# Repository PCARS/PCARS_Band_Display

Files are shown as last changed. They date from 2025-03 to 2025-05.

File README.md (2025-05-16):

# PCARS W4MLB Club Station Band Display

## Technical Project Summary

This project was developed for the Platinum Coast Amateur Radio Club (PCARS) to improve operational coordination at the W4MLB Club Station. It features a shared LED display that shows the active operating band and mode for two radio stations (Station 1 and Station 2), helping operators avoid frequency conflicts and manage dual-station operation more effectively.

---

## System Overview

The Band Display system consists of:

1. **ESP32-Based Control Unit**  
2. **Single Shared 64x64 RGB LED Matrix Display**  
3. **Audible Conflict Alert System**

<table>
  <tr>
    <td align="center">
      <br/>
      <sub>PCARS Band Display</sub>
    </td>
  </tr>
</table>

---

## Hardware Details

### Microcontroller
- **ESP32 DevKit V1**
  - Dual-core 32-bit microcontroller with Wi-Fi and Bluetooth
  - Interfaces with both radios via CI-V communication over UART
  - Processes band/mode data and drives the shared LED matrix display and alert system

### Display System
- **Single 64x64 RGB LED Matrix (HUB75 interface)**
  - Displays operating band and mode for both stations side-by-side
  - Color-coded segments for easy visual distinction between Station 1 and Station 2
  - Driven using the [ESP32-HUB75-MatrixPanel-I2S-DMA library](https://github.com/mrfaptastic/ESP32-HUB75-MatrixPanel-I2S-DMA) for high-performance, flicker-free display updates

### Radio Interface (Band/Mode Input)
- **CI-V Serial Bus Communication**
  - Each radio communicates band/mode data to the ESP32 via CI-V protocol
  - CI-V signals are connected to separate UART RX/TX pairs on the ESP32
  - Enables automated and accurate detection of each radio’s current state

### Power Supply
- **5V / 5A DC Input via 2.5mm Barrel Jack and Inline Mini Fuse Holder**
- **2-Position Screw Terminal for powering the LED matrix directly**, ensuring stable high-current delivery

### Alert System
- **Passive Buzzer (controlled via GPIO)**
  - Activates after 3 seconds if both stations are tuned to the same band
  - Logic controlled by the ESP32 to help operators avoid interference

### Connectors
- **2x8 Female Header (Bottom) + 2x8 Male Ribbon Header (Top)**
  - Used to interface the ESP32 Control Board to the LED matrix
  - Bottom connector allows direct plug-in to the matrix input (back-side mounting)
  - Top connector allows connection via standard ribbon cable

### PCB Design
- **2-layer Custom PCB**
  - Top layer features a +5V copper fill for power distribution
  - Bottom layer contains a solid ground pour with signal traces routed within
  - Compact and purpose-built layout for minimal noise and easy integration with the LED matrix

## Key Features
- Shared 64x64 LED matrix with real-time band/mode display for both stations  
- CI-V-based band/mode input over UART for accurate radio status monitoring  
- Conflict alert system buzzer with 3-second delay 
- ESP32-driven logic with efficient HUB75 display handling  
- Clean power distribution with dedicated matrix power input

## Software

The Band Display firmware is developed using the **Arduino framework** within **PlatformIO** on **Microsoft Visual Studio Code**. It leverages the multitasking capabilities of the ESP32 and includes purpose-built logic for real-time display updates, radio state monitoring, and conflict alerts.

### Key Components

- **PlatformIO Environment**  
  Ensures reproducible builds and dependency management.  
  Configuration is defined in `platformio.ini`.

- **ESP32-HUB75-MatrixPanel-I2S-DMA Library**  
  Handles high-speed updates to the 64x64 HUB75 RGB LED matrix.  
  This library utilizes the **ESP32's built-in DMA hardware** to stream pixel data directly to the matrix via the I2S peripheral.  
  Because the DMA engine manages the actual data transfer, the **main processor cores remain free** for other tasks such as serial parsing, logic processing, and display updates.  
  This results in **flicker-free, high-performance rendering** with minimal CPU overhead.  
  GitHub: [ESP32-HUB75-MatrixPanel-I2S-DMA](https://github.com/mrfaptastic/ESP32-HUB75-MatrixPanel-I2S-DMA)

- **CI-V Decoder Logic**  
  Parses incoming CI-V data from both radios over two **dedicated hardware UARTs** on the ESP32.  
  Using hardware UART peripherals ensures that incoming serial data is buffered and handled by the UART hardware itself—**without blocking or interrupting the main program flow**.  
  This allows for **reliable and real-time decoding** of Icom/Yaesu CI-V messages, even when both radios are transmitting data simultaneously.

- **Display Management**  
  Color-coded band/mode segments for each station.  
  Adaptive text sizing and positioning to fit the matrix resolution.  
  Designed to update dynamically based on the latest decoded band and mode data for each station.

- **Conflict Alert System**  
  When both stations are detected operating on the same band, a **passive buzzer** is used to annunciate the conflict.  
  The buzzer is driven using one of the **ESP32’s built-in PWM channels**, which allows tone generation **without burdening the processor with manual timing or waveform control**.  
  This hardware-driven approach ensures accurate and non-blocking sound output, keeping the main application responsive.

- **Task Scheduling**  
  Uses ESP32 FreeRTOS tasks for concurrent handling of:
  - CI-V communication  
  - Display updates  
  - Conflict alert logic  
  This structure allows each subsystem to operate independently without interfering with others, improving responsiveness and reliability.

  ---

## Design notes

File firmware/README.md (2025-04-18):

This folder contains firmware files for the ESP32 DevKit V1 board that is used to drive a 64x64 HUB75 P3 LED Matrix display.

The firmware also interfaces with the radio's CI-V busses by utilizing the onboard HW UARTS of the ESP32.

The firmware listens for changes to frequency and operating mode.

It can also query the radios on startup to initialize the LED display with the proper status information. (band and operating mode)

The firmware will also activate a warning buzzer if both stations are on the same operating band for more than 3 seconds.

The LED Matrix is driven by ESP32-HUB75-MatrixPanel-I2S-DMA library.

The firmware was developed using the Arduino framework utilizing PlatFormIO running inside MS VS Code. See the platformio.ini file for details.

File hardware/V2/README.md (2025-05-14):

This folder contains PCB design files for the PCARS Band Display interface/controller board.

This booard is designed to plug directly into the ribbon cable connector on the back side of a HUB75 LED Matrix.

It is small enough to fit inside the cavity behind the LED Matrix.

The board provide interfaces for CI-V buses from 2 different radios.

The board also has connections for a DC power supply to power the LED Matrix and ESP32 controller.

A passive buzzder is also included to allow for alerting when both radios are tuned to the same band.

The PCB was designed using the KiCAD design suite.

The Library folder contains sub-folders for the individual part's Symbols, Footprints and 3D models.

The parts library files were download primarily from the SnapEDA website.

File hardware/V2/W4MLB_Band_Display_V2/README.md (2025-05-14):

This folder contains PCB design files for the PCARS Band Display interface/controller board.

This booard is designed to plug directly into the ribbon cable connector on the back side of a HUB75 LED Matrix.

It is small enough to fit inside the cavity behind the LED Matrix.

The board provide interfaces for CI-V buses from 2 different radios.

The board also has connections for a DC power supply to power the LED Matrix and ESP32 controller.

A passive buzzder is also included to allow for alerting when both radios are tuned to the same band.

The PCB was designed using the KiCAD design suite.

The Library folder contains sub-folders for the individual part's Symbols, Footprints and 3D models.

The parts library files were download primarily from the SnapEDA website.
### Images:

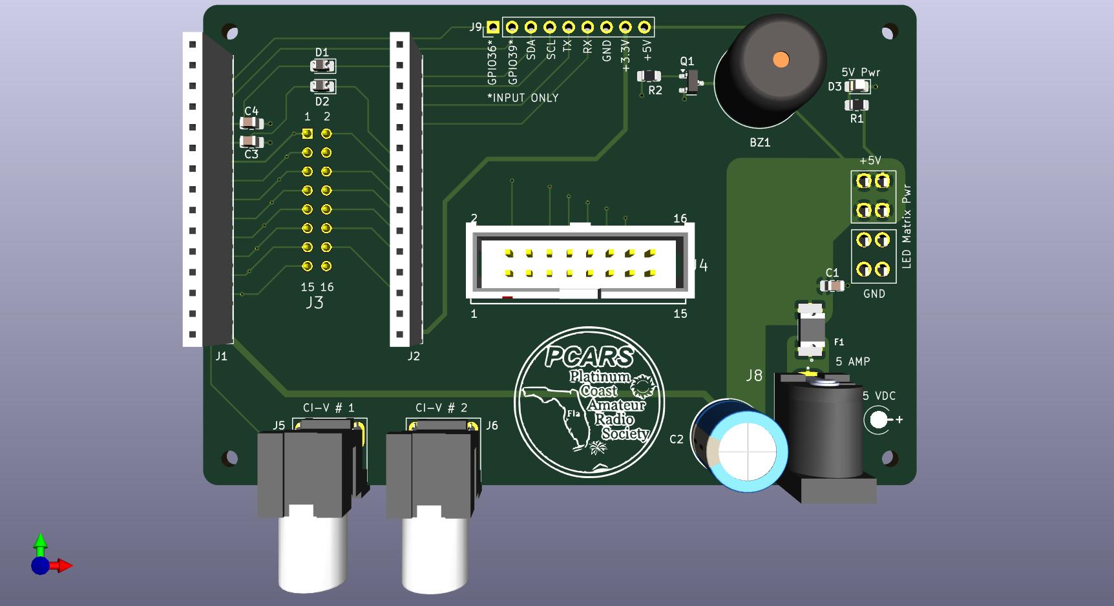
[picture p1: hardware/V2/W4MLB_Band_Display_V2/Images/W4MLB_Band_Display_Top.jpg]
Top View

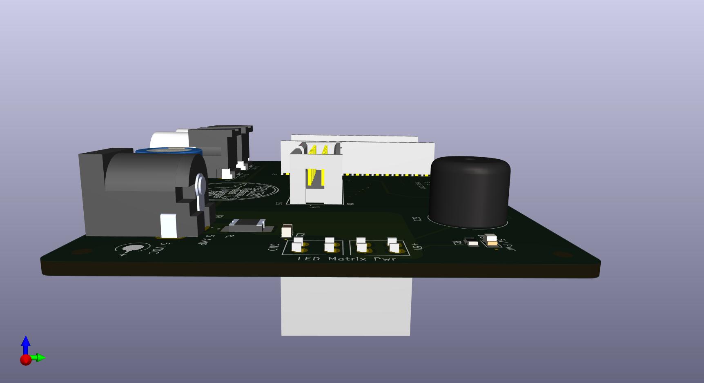
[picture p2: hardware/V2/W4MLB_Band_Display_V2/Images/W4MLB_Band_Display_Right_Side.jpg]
Right Side View

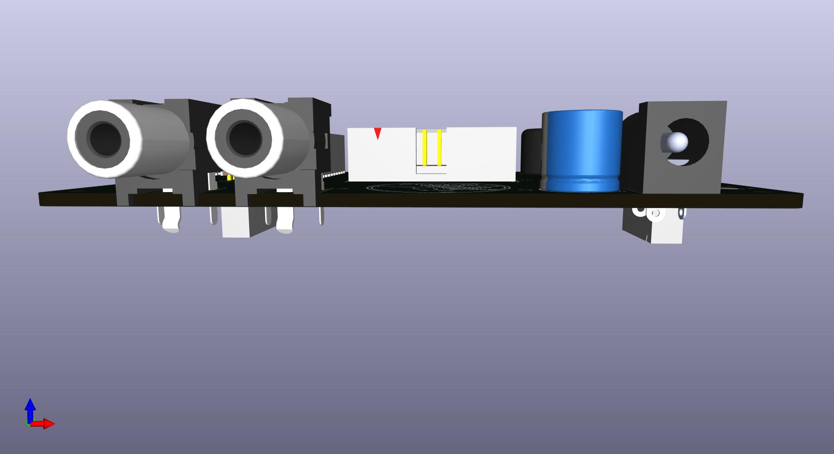
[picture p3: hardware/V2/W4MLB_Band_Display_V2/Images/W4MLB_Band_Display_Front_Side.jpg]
Front Side View

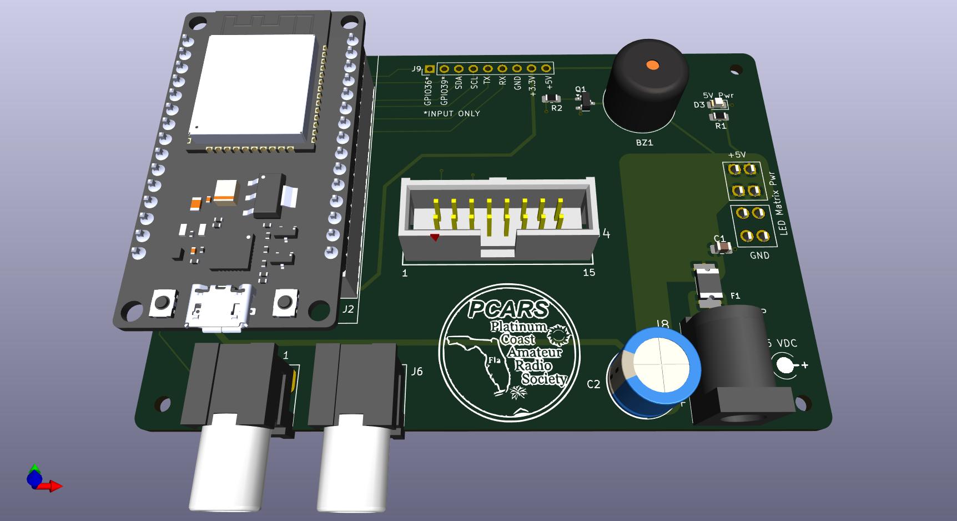
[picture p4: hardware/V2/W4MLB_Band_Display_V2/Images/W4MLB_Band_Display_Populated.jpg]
Populated Board

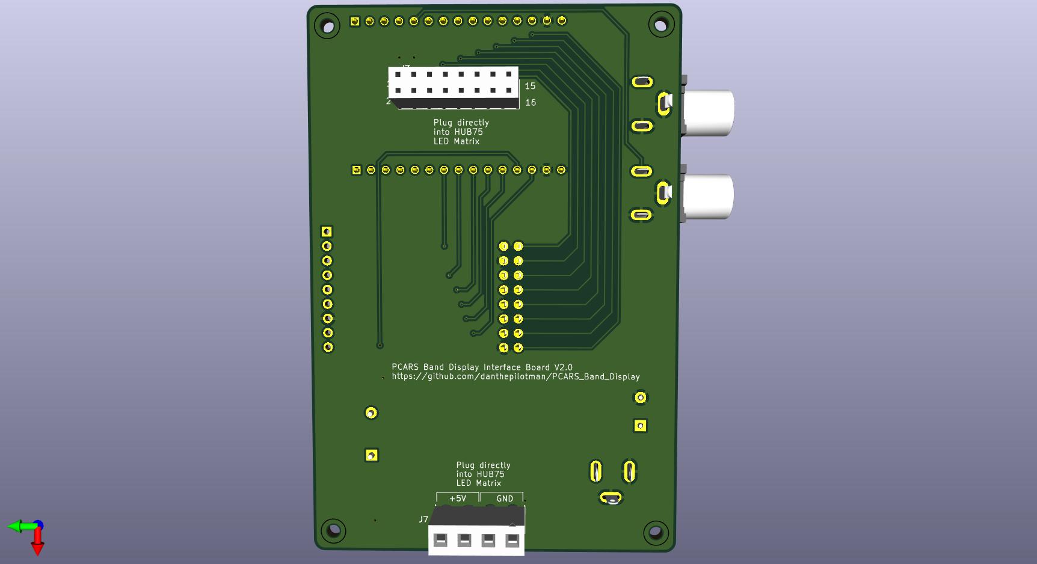
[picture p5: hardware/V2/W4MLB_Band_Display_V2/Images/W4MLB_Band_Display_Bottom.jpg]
Bottom View


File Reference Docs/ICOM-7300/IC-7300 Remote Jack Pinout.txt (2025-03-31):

Tip ->  CI-V data
Ring -> NC
Sleeve -> GND

Connections

    IC-7300 (Remote Jack) → Optocoupler Input

        Tip → Optocoupler Anode (+)

        Sleeve (GND) → Optocoupler Cathode (-)
	
	390Ω current limiting resistor

	R = (5V - 1.2V) / 10mA  
	R = 3.8V / 10mA  
	R = 380Ω (round to 390Ω for safety)

    Optocoupler Output (Transistor Side) → Arduino

        Collector → Arduino RX Pin (e.g., D2 for Radio 1, D3 for Radio 2)

        Emitter → GND

        4.7kΩ Pull-up resistor between the collector and 5V to ensure proper signal reading.

The pull-up resistor for the CI-V bus is inside the radio, but its presence and value depend on the specific Icom model and settings.
Inside the Radio:

    Most Icom radios (including the IC-7300) have an internal pull-up resistor on the CI-V data line.

    The typical value is around 4.7kΩ - 10kΩ, pulling the line up to 5V.

    This allows multiple devices (tuner, amp, PC, etc.) to share the same single-wire bus.

How to Check If a Pull-Up Resistor Exists

    Measure Voltage on the CI-V Tip (Idle State)

        Disconnect any external CI-V devices.

        Use a multimeter to measure the voltage between the tip (data line) and sleeve (ground) of the 3.5mm CI-V jack.

        If the voltage is ~5V, the radio has an internal pull-up.

        If the voltage is ~0V, the radio may not have a pull-up, or it only activates when a device is connected.

    Use an Oscilloscope or Logic Analyzer

        Observe the CI-V bus while the radio transmits data.

        If the high level is weak or unstable, an external pull-up may help.

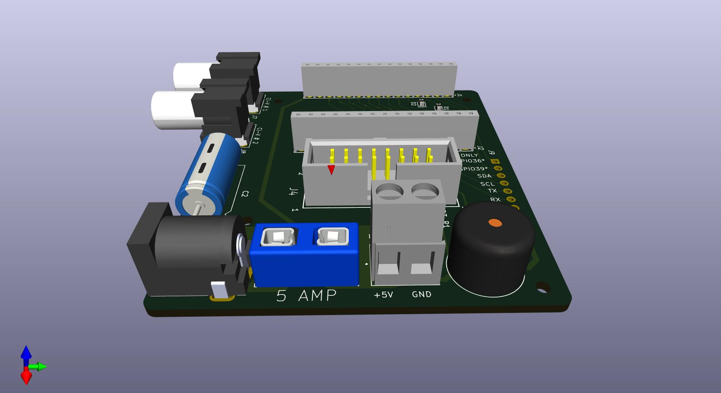
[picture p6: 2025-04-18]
hardware/V2/Images/W4MLB_Band_Display_Right_Side.jpg

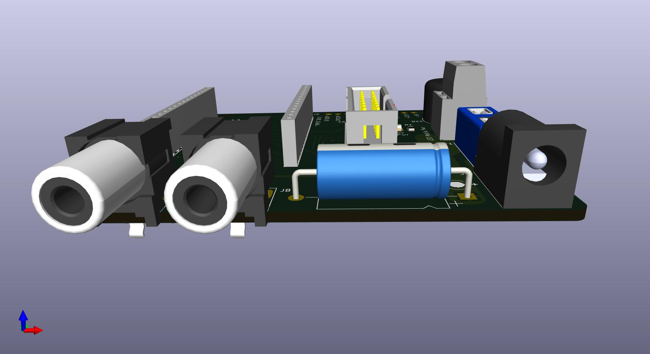
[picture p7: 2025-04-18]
hardware/V2/Images/W4MLB_Band_Display_Front_Side.jpg

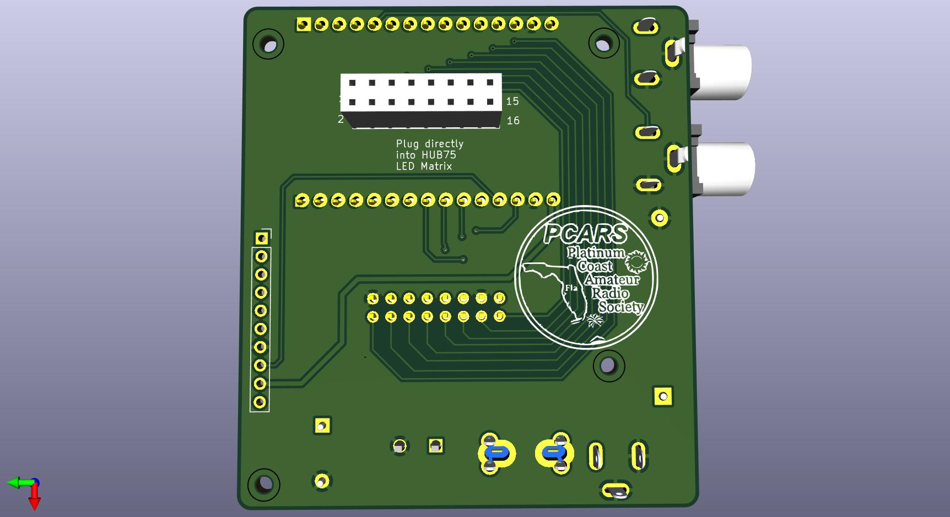
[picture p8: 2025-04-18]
hardware/V2/Images/W4MLB_Band_Display_Bottom.jpg

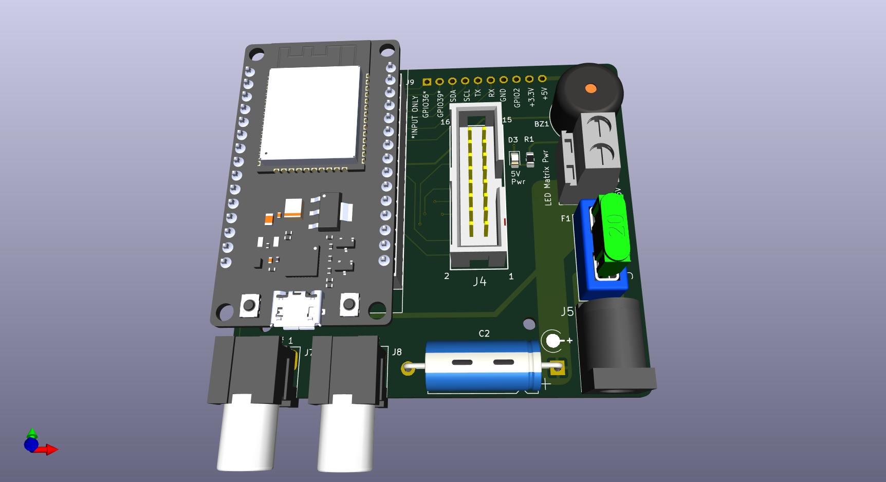
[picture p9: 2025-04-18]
hardware/V2/Images/W4MLB_Band_Display_Populated.jpg

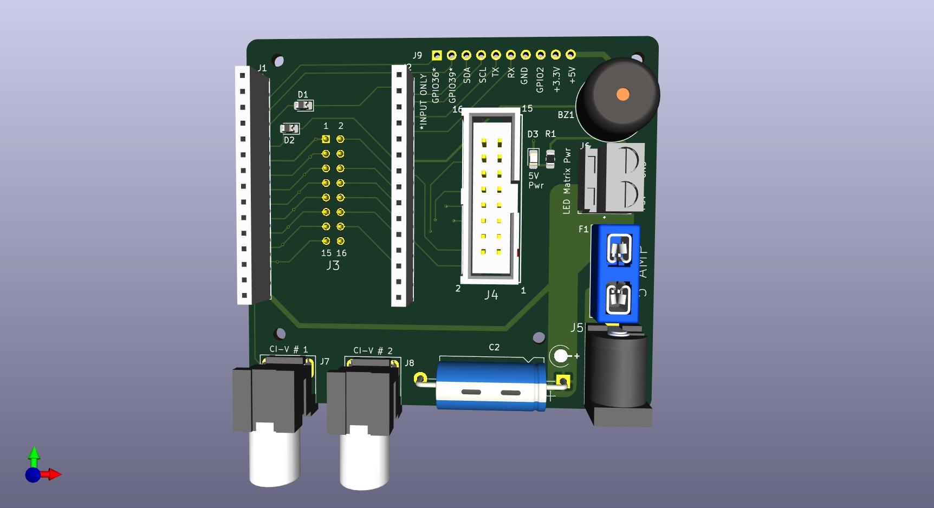
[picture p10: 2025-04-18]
hardware/V2/Images/W4MLB_Band_Display_Top.jpg

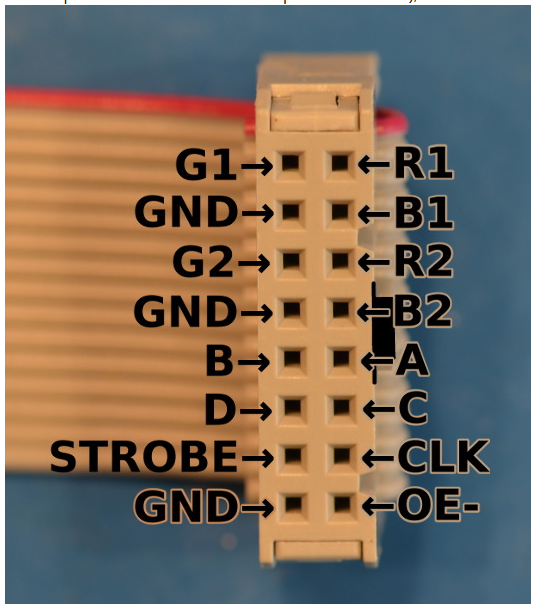
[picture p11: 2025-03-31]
Reference Docs/64x64 LED Matrix Connector Pinout.PNG

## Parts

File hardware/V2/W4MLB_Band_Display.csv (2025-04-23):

Reference | Qty | Value | DNP | Exclude from BOM | Exclude from Board | Footprint | Datasheet
BZ1 | 1 | Buzzer |  |  |  | Buzzer_Beeper:Buzzer_12x9.5RM7.6 | kicad-embed://cmi_1295_05th-3513106.pdf
C1,C3,C4 | 3 | 4.7nF |  |  |  | Capacitor_SMD:C_0805_2012Metric_Pad1.18x1.45mm_HandSolder | kicad-embed://KGM_X7R-3223212.pdf
C2 | 1 | 2200uF |  |  |  | Capacitor_THT:CP_Radial_D10.0mm_P5.00mm | kicad-embed://ABA0000C1218.pdf
D1,D2 | 2 | 1N4001 |  |  |  | Diode_SMD:D_0805_2012Metric_Pad1.15x1.40mm_HandSolder | kicad-embed://TS4148 SERIES_A2301.pdf
D3 | 1 | LED |  |  |  | LED_SMD:LED_0805_2012Metric_Pad1.15x1.40mm_HandSolder | kicad-embed://Lite_On_LTST_C170KGKT-1175299.pdf
F1 | 1 | Polyfuse |  |  |  | Footprints:FUSE_1812L200_12DR | kicad-embed://1812L300SLPR_Littelfuse.pdf
J1,J2 | 2 | SSW-115-01-G-S |  |  |  | Footprints:SAMTEC_SSW-115-01-G-S | kicad-embed://SSW-115-01-G-S_Samtec.pdf
J3 | 1 | SSQ-108-01-T-D-LL |  |  |  | Footprints:SAMTEC_SSQ-108-01-T-D-LL | kicad-embed://SSQ-108-01-T-D-LL_Samtec.pdf
J4 | 1 | SAMTEC-TST-108-01-X-D |  |  |  | Footprints:SAMTEC-TST-108-01-X-D | kicad-embed://tst-1xx-xx-x-x-xx-xx-mkt.pdf
J5,J6 | 2 | PJRAN1X1U01X |  |  |  | Footprints:SWITCHCRAFT_PJRAN1X1U01X | kicad-embed://PJRAN1X1U01X_Switchcraft.pdf
J7 | 1 | 4DB-P108-02 |  |  |  | Footprints:CONN_4DB-P108-02_TEC | 4DB-P108-02
J8 | 1 | EJ503B |  |  |  | Footprints:MPD_EJ503B | kicad-embed://EJ503B_MPD_(Memory.pdf
J9 | 1 | Conn_01x09 |  |  |  | Connector_PinHeader_2.54mm:PinHeader_1x09_P2.54mm_Vertical | ~
Q1 | 1 | MMBT2222A |  |  |  | Package_TO_SOT_SMD:SOT-23 | kicad-embed://mmbt2222.pdf
R1 | 1 | 150 |  |  |  | Resistor_SMD:R_0805_2012Metric_Pad1.20x1.40mm_HandSolder | kicad-embed://crcwce3.pdf
R2 | 1 | 470 |  |  |  | Resistor_SMD:R_0805_2012Metric_Pad1.20x1.40mm_HandSolder | kicad-embed://PYu_AC_51_RoHS_L_9-3005297.pdf
U1 | 1 | ESP32-DEVKIT-V1 | DNP | Excluded from BOM | Excluded from board | Footprints:MODULE_ESP32_DEVKIT_V1

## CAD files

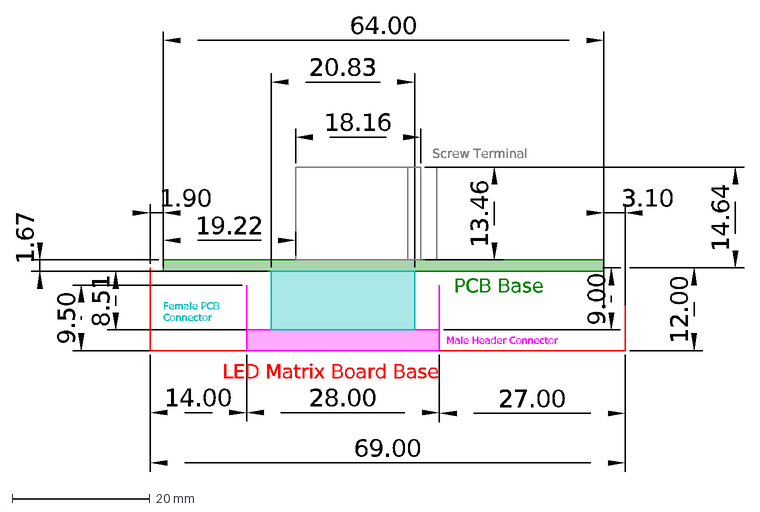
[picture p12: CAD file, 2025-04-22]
hardware/V2/Mechanical_CAD/Mechanical_Stack_Up.dxf
PCB Base
64.00
12.00
14.00
28.00
9.50
69.00
27.00
1.90
9.00
20.83
8.51
Male Header Connector
Female PCB Connector
LED Matrix Board Base
1.67
13.46
19.22
18.16
14.64
3.10
Screw Terminal

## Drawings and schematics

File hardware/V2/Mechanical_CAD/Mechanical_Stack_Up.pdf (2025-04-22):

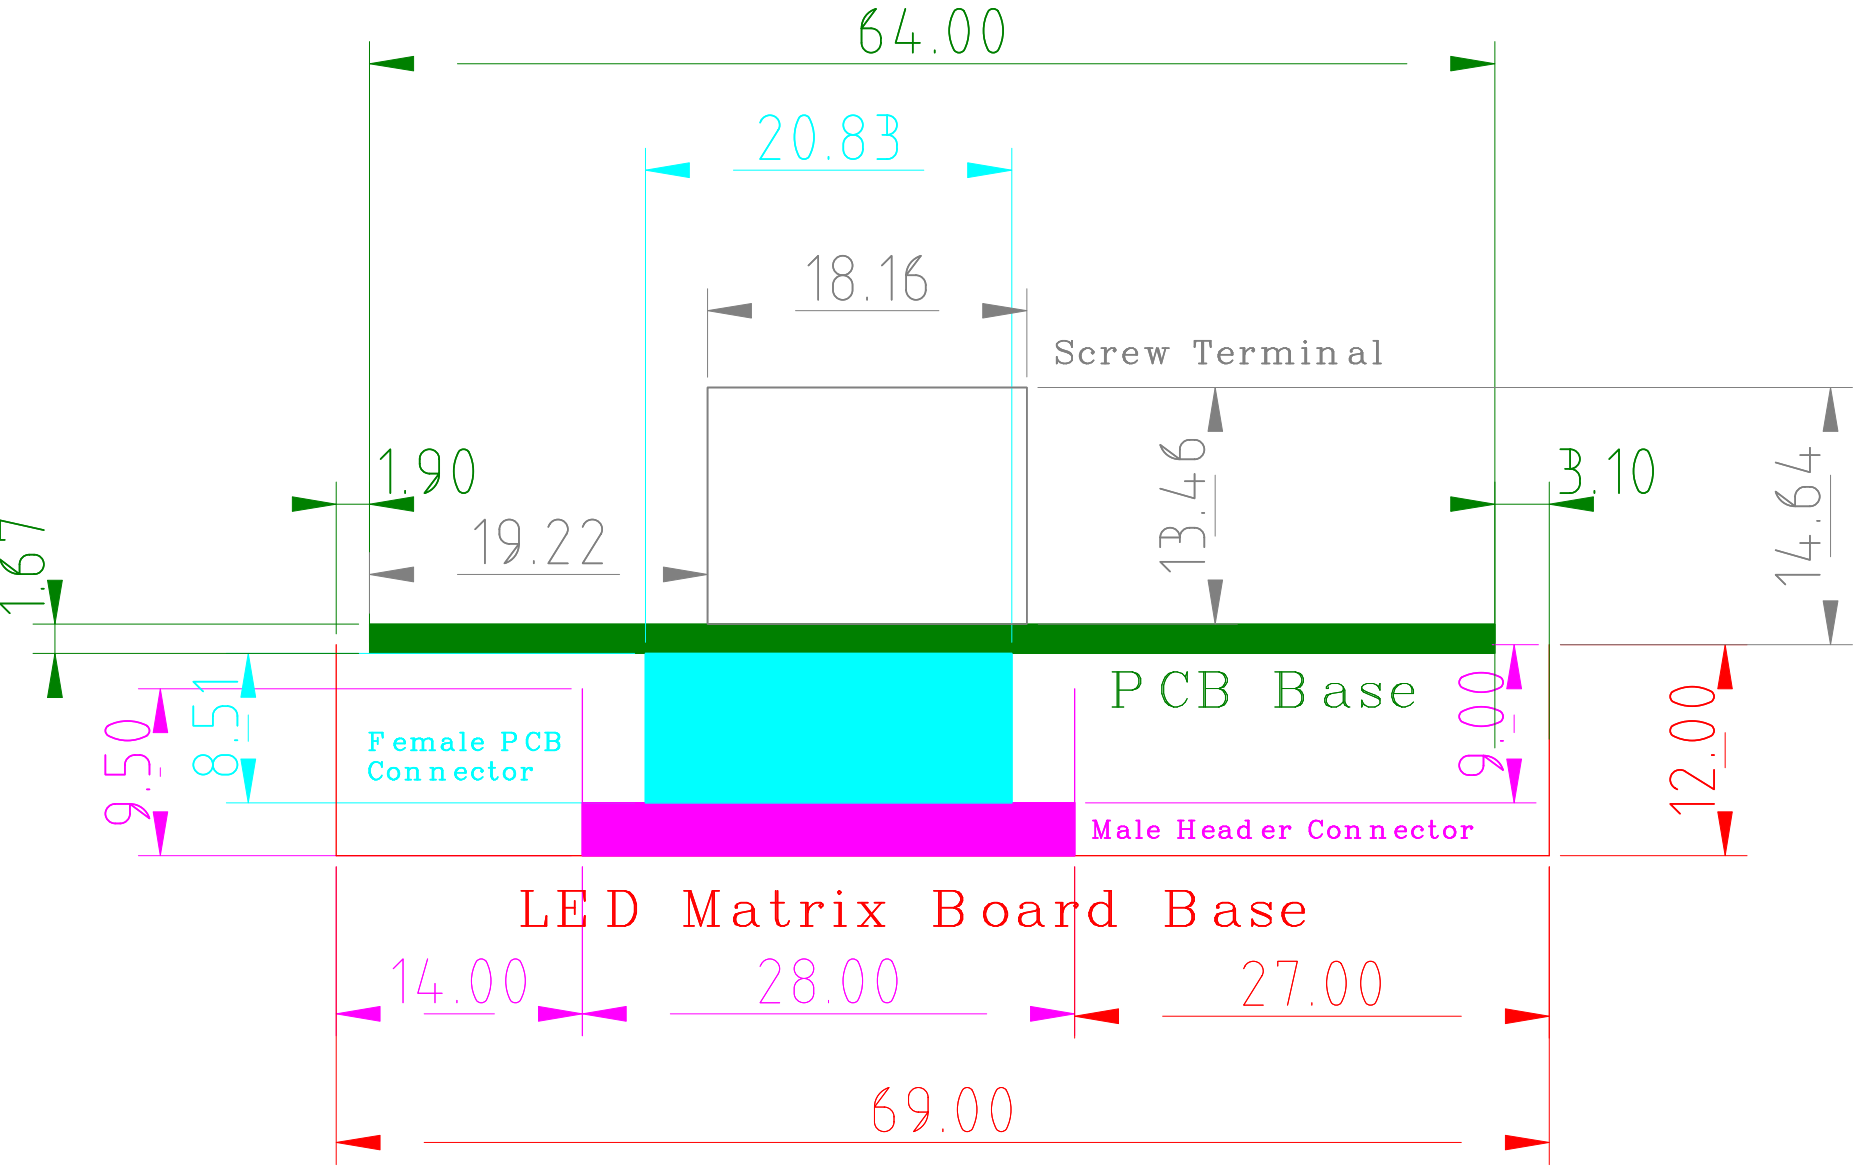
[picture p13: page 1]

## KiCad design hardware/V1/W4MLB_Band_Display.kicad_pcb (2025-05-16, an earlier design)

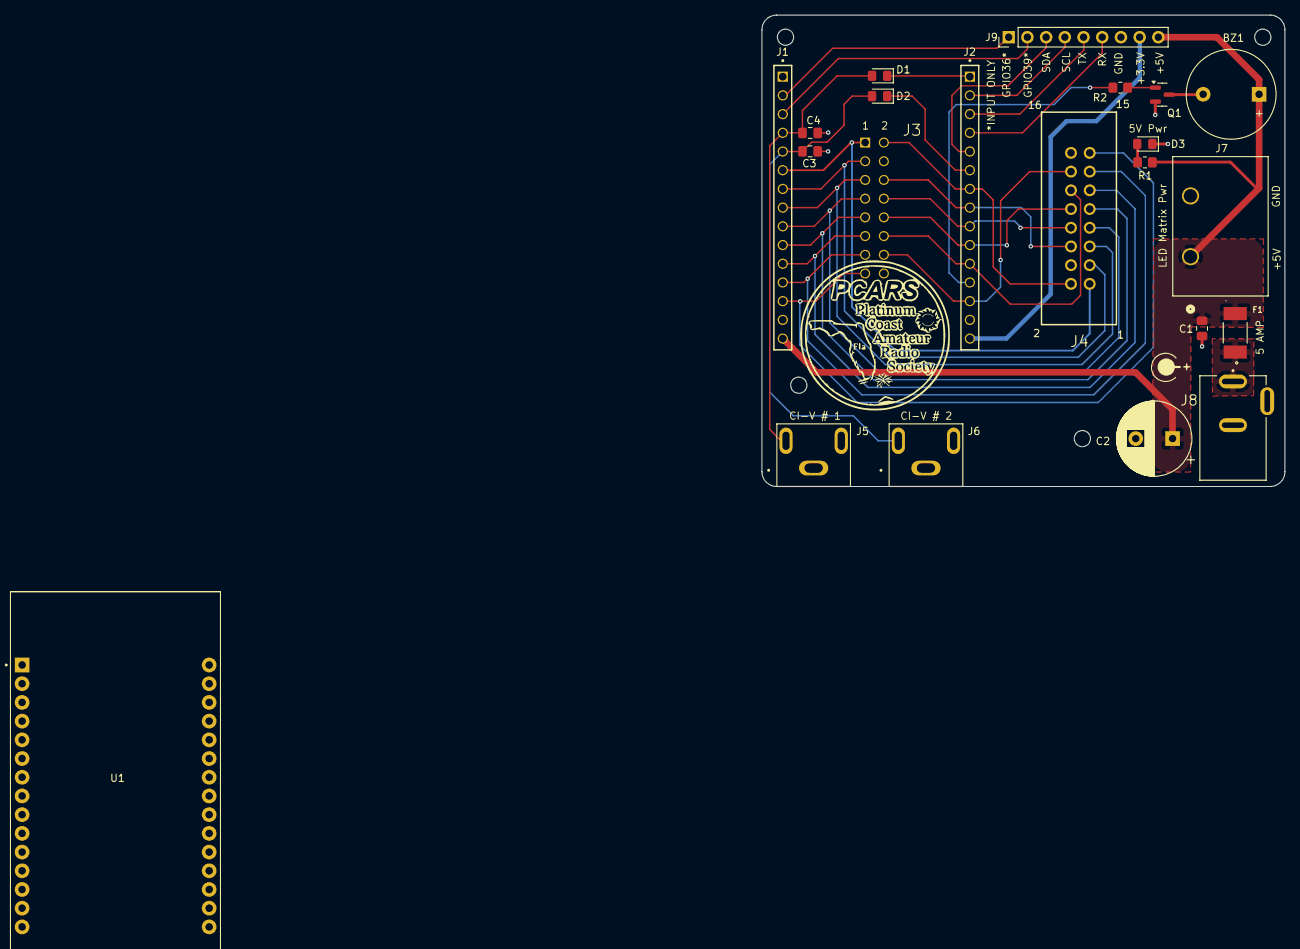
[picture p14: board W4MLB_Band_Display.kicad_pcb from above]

Board: 2 copper layers, 71.0 x 64.0 mm, 26 parts (1 on the bottom side), 32 nets.

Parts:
BZ1: Buzzer; Buzzer_12x9.5RM7.6
C1, C3, C4: 4.7nF; C_0805_2012Metric_Pad1.18x1.45mm_HandSolder
C2: 2200uF; CP_Radial_D10.0mm_P5.00mm
D1, D2: 1N4001; D_0805_2012Metric_Pad1.15x1.40mm_HandSolder
D3: LED; LED_0805_2012Metric_Pad1.15x1.40mm_HandSolder
F1: Polyfuse; FUSE_1812L200_12DR
J1, J2: SSW-115-01-G-S; SAMTEC_SSW-115-01-G-S
J3: SSQ-108-01-T-D-LL; SAMTEC_SSQ-108-01-T-D-LL
J4: SAMTEC-TST-108-01-X-D
J5, J6: PJRAN1X1U01X; SWITCHCRAFT_PJRAN1X1U01X
J7: 4DB-P108-02; CONN_4DB-P108-02_TEC
J8: EJ503B; MPD_EJ503B
J9: Conn_01x09; PinHeader_1x09_P2.54mm_Vertical
MH1, MH2, MH3, MH4: MountingHole_2.2mm_M2
Q1: MMBT2222A; SOT-23
R1: 150; R_0805_2012Metric_Pad1.20x1.40mm_HandSolder
R2: 470; R_0805_2012Metric_Pad1.20x1.40mm_HandSolder
U1: ESP32-DEVKIT-V1; MODULE_ESP32_DEVKIT_V1

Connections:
+5V: BZ1.1 (+), C1.1, C2.1, F1.2, J1.15, J7.1, J9.9, R1.2
/+3.3VDC: J2.15, J9.8
/PWR IN: F1.1, J8.1
GND: C1.2, C2.2, C3.2, C4.2, D3.1 (K), J1.14, J2.14, J3.04, J3.16, J4.4, J4.16, J5.1, J5.3, J6.1, J6.3, J7.2, J8.2, J8.3, J9.7, Q1.2 (E)
GPIO1: J2.03, J9.5
GPIO2: J2.12, R2.1
GPIO3: J2.04, J9.6
GPIO4: J2.11, J3.12, J4.12
GPIO5: J2.08, J3.06, J4.6
GPIO12: J1.12, J3.13, J4.13
GPIO13: J1.13, J3.15, J4.15
GPIO14: J1.11, J3.11, J4.11
GPIO15: J2.13, J3.14, J4.14
GPIO16: J2.10, J3.10, J4.10
GPIO17: J2.09, J3.08, J4.8
GPIO18: J2.07, J3.02, J4.2
GPIO19: D2.1 (K), J2.06
GPIO21: J2.05, J9.3
GPIO22: J2.02, J9.4
GPIO23: D1.1 (K), J2.01
GPIO25: J1.08, J3.05, J4.5
GPIO26: J1.09, J3.07, J4.7
GPIO27: J1.10, J3.09, J4.9
GPIO32: J1.06, J3.01, J4.1
GPIO33: J1.07, J3.03, J4.3
GPIO34: C4.1, D1.2 (A), J1.04, J5.2
GPIO35: C3.1, D2.2 (A), J1.05, J6.2
GPIO36: J1.02, J9.1
GPIO39: J1.03, J9.2
unnamed: BZ1.2 (-), Q1.3 (C)
unnamed: D3.2 (A), R1.1
unnamed: Q1.1 (B), R2.2

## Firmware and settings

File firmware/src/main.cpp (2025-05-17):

/*
   This program receives CI-V data from two radio stations (Radio 1 & Radio 2)
   using serial communication. The CI-V protocol provides real-time updates on
   each radio's operating band, mode, and TX/RX status.

   The received data is processed to extract relevant information, and the
   64x64 LED matrix display is updated accordingly. Each radio's status is
   visually represented on the matrix, ensuring clear and immediate feedback
   on their operational states.

   - Radio 1 and Radio 2 CI-V data is received via separate serial inputs.
   - The program decodes the band and mode from the incoming CI-V packets.
   - The LED matrix is updated dynamically to reflect changes for each radio.
*/


#include "Setup.h"
#include "CI-V.h"
#include "Display.h"


void setup()
{

  setup_PWM();  // Setup PWM for driving passive buzzer
  
  setup_Serial();  // Setup serial ports for printing and CI-V radio communication
    
  setup_LED_Display();  // Setup LED Matrix display and display default settings

  setup_WIFI();

  setup_NTP();

  Serial.println( F( "Listening to IC-7300 radio(s)..." ) );  // Print that program is ready to receive CI-V data

}


void loop()
{

  radio1_active =  query_Radio( Serial1, 1 );  // Check for CI_V activity from Radio 1

  radio2_active =  query_Radio( Serial2, 2 );  // Check for CI_V activity from Radio 2

  update_Display();  // Update display if changes occurred

  band_Conflict_Check();  // Check for band conflicts and alert if needed

  delay( LOOP_DELAY );  // Delay to prevent excessive traffic on the CI-V bus
  
}

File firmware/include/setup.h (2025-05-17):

#ifndef SETUP_H
#define SETUP_H

#include <Arduino.h>       // Required libarary for Arduino programming
#include <Adafruit_GFX.h>  // LED matrix library dependancy
#include <WiFi.h>
#include <time.h>

#define LOOP_DELAY 1000 // Loop delay [ms] to avoid excessive CI-V traffic

#define BUZZER_PIN 2  // Assign pin to drive passive buzzer with PWM
#define BUZZER_FREQUENCY 2400  // 2.5kHz typically close to buzzer resonant frequency
#define BUZZER_CHANNEL 0  // Assign a PWM channel to the buzzer


#define SERIAL_BAUD 115200  // Baud rate for printing

#define CI_V_BAUD 19200  // Change if needed to match radio's baud date
#define RX_1 34  // Radio Station 1 UART RX pin
#define TX_1 23  // Radio Station 1 UART TX pin
#define RX_2 35  // Radio Station 2 UART RX pin
#define TX_2 19  // Radio Station 2 UART TX pin


// Define the panel configuration to override defaults in library
#define MATRIX_WIDTH 64   // Matrix panel width in pixels
#define MATRIX_HEIGHT 64  // Matrix panel height in pixels
#define MATRIX_CHAIN 1    // Number of panels chained together
#define LED_MATRIX_DRIVER HUB75_I2S_CFG::FM6124  // Specific driver based on IC installed on LED matrix


#include <ESP32-HUB75-MatrixPanel-I2S-DMA.h>  // LED matrix library

// ESP32 DevKit Pin Definitions (Avoiding Serial1 and Serial2 conflicts)
// See 64x64 LED Matrix Connector Pinout.PNG in Reference Docs folder

// Right side of ribbon cable with connector facing towards you, red stripe up
#define P_R1  32
#define P_B1  33
#define P_R2  25
#define P_B2   26
#define P_A   27
#define P_C   14
#define P_CLK 12
#define P_OE  13

// Left side of ribbon cable with connector facing towards you, red stripe up
#define P_G1  18
// GND PIN
#define P_G2  5
#define P_E   17 // Required for 64x64 LED Matrix
#define P_B   16
#define P_D   4
#define P_LAT 15  // A.K.A. Strobe
// GND PIN


// Define color codes, RGB565 format, eg 0xFFFF = 11111 111111 11111 = white
//                                                RRRRR GGGGGG BBBBB
#define BLACK       0x0000  // 0
#define NAVY        0x000F  // 15
#define DARKGREEN   0x03E0  // 992
#define DARKCYAN    0x03EF  // 1007
#define MAROON      0x7800  // 30720
#define PURPLE      0x780F  // 30735
#define OLIVE       0x7BC0  // 31712
#define LIGHTGREY   0xC618  // 50712
#define DARKGREY    0x7BEF  // 31727
#define BLUE        0x001F  // 31
#define GREEN       0x07E0  // 2016
#define CYAN        0x07FF  // 2047
#define RED         0xF800  // 63488
#define MAGENTA     0xF81F  // 63519
#define YELLOW      0xFFE0  // 65504
#define WHITE       0xFFFF  // 65535
#define ORANGE      0xFD20  // 64800
#define GREENYELLOW 0xB7E5  // 45029
#define PINK        0xFC9C  // 64536


#define BRIGHTNESS 90  // LED Matrix pixel brightness 0 - 255, 90 is a good mid-range level

#define STATION_LABEL_COLOR YELLOW  // Determine color for station labels
#define STATION_1_COLOR MAGENTA  // Determine color for station # 1
#define STATION_2_COLOR CYAN     // Determine color for station # 2


#define CHAR_HEIGHT   7  // Height of displayed characters in pixels
#define CHAR_WIDTH    5  // Width of displayed characters in pixels
#define LEFT_MARGIN   1  // Margin from left side of display in pixels
#define RIGHT_MARGIN  1  // Margin from right side of display in pixels
#define MAX_NUM_CHARS 5  // Max num of chars = 5, eg. 80/40, 1000W
#define TEXT_BOX_WIDTH ( MAX_NUM_CHARS * CHAR_WIDTH + MAX_NUM_CHARS - 1 ) // 5*5 + (5-1) = 25 + 4 = 29
#define TEXT_BOX_X ( MATRIX_WIDTH - RIGHT_MARGIN - TEXT_BOX_WIDTH )
#define ROW_SEPARATION 10  // Space between displayed rows
#define FIRST_ROW_Y 1  // Y-value of the first displayed row, 0,0 is top left of display
#define SECOND_ROW_Y FIRST_ROW_Y  +  ROW_SEPARATION  // Y-value of the 2nd displayed row.
#define THIRD_ROW_Y  SECOND_ROW_Y +  ROW_SEPARATION  // Y-value of the 2nd displayed row
#define FOURTH_ROW_Y THIRD_ROW_Y  +  ROW_SEPARATION  // Y-value of the 3rd displayed row
#define FIFTH_ROW_Y FOURTH_ROW_Y  +  ROW_SEPARATION  // Y-value of the 4th displayed row
#define SIXTH_ROW_Y FIFTH_ROW_Y   +  ROW_SEPARATION  // Y-value of the 5th displayed row
#define SEVENTH_ROW_Y SIXTH_ROW_Y +  ROW_SEPARATION  // Y-value of the 6th displayed row


extern MatrixPanel_I2S_DMA matrix;  // Matrix instantiation

extern const char* ssid;
extern const char* password;

#define NTP_TIMEOUT 10 // Time in [s] before NTP time acquisition times out

extern const char* ntpServer;  // Path to NTP server
extern struct tm timeinfo;  // Structure for holding time information

// Function prototypes
void setup_PWM();
void setup_Serial();
void setup_LED_Display();
uint8_t calculateTextWidth(String text);
void  setup_WIFI();
void printWifiStatus();
void setup_NTP();


#endif

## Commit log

2025-03-28 First commit. Basic CI-V receive capability. Also added LED Matrix display capability.
2025-04-10 Reverted back to using Strings. Const char* was causing runtime crashes. Added query capability to initliaze display.
    [CI-V.cpp, CI-V.h, setup.cpp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]
2025-04-10 Added #define for start of message (0xFE) Added #define for LED brightness Formatted spacing Added remaining print statements to utilize F( ) macro Modified query commands into a 2 dimensional array 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
2025-04-12 Initial Cpmmit
    [W4MLB_Band_Display.kicad_pcb, W4MLB_Band_Display.kicad_sch]
2025-04-14 First release candidate draft
    Laid out components and routed signals. Added silkscreen text and artwork
    [HQ NextPCB Simple.kicad_pcb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]
2025-04-17 Adjusted RX pins to input only pins to save GPIO. Removed placeholder text for Amp power, antenna and RX/TX. Added band conflict checker.
2025-04-17 Removed printing of redundant units for band
2025-04-17 Buzzer
    Added buzzer. Rearranged pins to make use of INPUT only pins for RX. Also reallocated different pins to the spare pins header and placed it in a better location.
    [W4MLB_Band_Display.kicad_pcb, W4MLB_Band_Display.kicad_sch]
2025-04-17 Updated platform to 6.10.0 latest version. Modified platform to DevKit -V1 instead of generic. Removed #define for LED_BUILTIN, Removed "New" from print "New Band". Renamed ledOn to led_On. Added a f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
2025-04-18 Finisghing touches
    Added fillets and chamfers to Cu zones. Adjusted silkscreen text and graphics.
    Added mounting holes.
    [W4MLB_Band_Display.kicad_pcb, W4MLB_Band_Display.kicad_sch]
2025-04-18 Move KiCad files to hardware/
    [HQ NextPCB Simple.kicad_pcb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]
2025-04-18 Update README.md
    Added board bottom view.
2025-04-18 Added 3D model images.
    [W4MLB_Band_Display.kicad_pcb]
2025-04-18 Added code to drive passive buzzer for band conflict alerts.
    [CI-V.cpp, main.cpp, setup.cpp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]
2025-04-18 Screw terminal connector & Datasheets
    Replaced LED Matric power connector with 2 position screw terminal for spade terminals. Also added datasheets for connector parts.
    [W4MLB_Band_Display.kicad_pcb, W4MLB_Band_Display.kicad_sch]
2025-04-19 Added LibreCAD drawing
    CAD drawing shows vertical stack up of parts. Also shows clearance from top and bottom side of PCB to LED Matrix cavity.
    [Mechanical_Stack_Up.dxf]
2025-04-19 Created Mech CAD folder.
    Moved dxf CAD design files to new folder. Created PDF for easy viewing.
    [Mechanical_Stack_Up.dxf]
2025-04-19 Removed rogue file
    [#Mechanical_Stack_Up.dxf]
2025-04-19 Clean up of dxf files
    [Mechanical_Stack_Up.dxf]
2025-04-20 Moved Ref Docs & Corrected Buzzer pin
    Moved Reference docs from /firmware/libs to Reference Docs at upper level.
    Fixed issue where GPIO19 was connected to both TX and Buzzer. Moved buzzer to GPIO2
    [W4MLB_Band_Display.kicad_pcb, W4MLB_Band_Display.kicad_sch]
2025-04-20 Cleaned up code for buzzer activation. Removed LED_BUILTIN digital pin code.
    [CI-V.cpp, main.cpp, setup.cpp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]
2025-04-20 Changed 10 pin connector to 9 pin
    Modified 10 pin connector to 9 pins after assignment of GPIO2 to buzzer and it no longer being a spare pin.
    [W4MLB_Band_Display.kicad_pcb]
2025-04-22 Smaller terminal block
    Changed terminal block to smaller footprint.
    Moved PCARS logo to front silkscreen.
    Added RF bypass caps to CI-V inputs.
    Adjusted location of D1 & D2.
    Modified F1 footprint to allow pins 3 &4 to be connected.
    [W4MLB_Band_Display.kicad_pcb, W4MLB_Band_Display.kicad_sch]
2025-04-22 Updated Mechanical Stack Up CAD Drawings
    Updated Mechanical Stack Up CAD Drawings to reflect change in terminal block connector dimensions.
    [Mechanical_Stack_Up.dxf]
2025-04-22 Added RF bypass cap to +5V DC supply input.
    [W4MLB_Band_Display.kicad_pcb, W4MLB_Band_Display.kicad_sch]
2025-04-22 Update RF decoupling caps to 4.7nF
    [W4MLB_Band_Display.kicad_sch]
2025-04-23 Added V2.0
    Added V2.0 which connects LED Matrix power via an onboard connector on the bottom of the board.
    [HQ NextPCB Simple.kicad_pcb, Mechanical_Stack_Up.dxf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]
2025-04-24 Fixed bug in code that prevented buzzer from triggering
    Fixed code to allow for buzzer to activate.
    Moved station #s down to second row.
    [CI-V.cpp, setup.h]
2025-04-24 Adjustment to parts locations
    [W4MLB_Band_Display_V2.kicad_pcb]
2025-04-30 Updates to V1 & V2 boards
    Updated location of +5V LED Matric power connector on V2 board after careful measurements.
    Made final changes to V1 board before sending off to fabrication.
    [W4MLB_Band_Display-B_Cu.gbr, W4MLB_Band_Display-B_Mask.gbr, W4MLB_Band_Display-B_Paste.gbr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]
2025-04-30 Consolidated drill file into Gerber folder
    Recompiled drill file into a single file and placed it inside the Gerber folder instead of it's own Drill folder.
    [W4MLB_Band_Display-NPTH.drl, W4MLB_Band_Display.drl]
2025-05-12 Updated firmware to handle when radios are off. Band conflict check now queries both radios to make sure they are on before triggering alarm.
    Also updated V1 of PCB with latest gerber files.
    [W4MLB_Band_Display-B_Cu.gbr, W4MLB_Band_Display-B_Mask.gbr, W4MLB_Band_Display-B_Paste.gbr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]
2025-05-14 Added and cleaned up comments. Swapped order of execution on band conflict and display update in loop function. Added code to clear displayed band and mode data if radio goes unresponsive to queries.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
    [CI-V.cpp, CI-V.h, main.cpp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]
2025-05-14 Updated images to reflect actual V1 build
    [W4MLB_Band_Display.kicad_pcb]
2025-05-14 Updated links to board 3D image files
2025-05-14 Removed links to 3D board images
2025-05-14 Updated V2 board 3D images
2025-05-14 Updated 3D board images
2025-05-14 Added HTML BOM to README for V1
2025-05-14 Change HTML BOM to a link
2025-05-14 Updated HTML BOM link text
2025-05-14 Added bold section text header for BOM link
2025-05-14 Swapped location of images and BOM
2025-05-14 Moved query_radio function prototype declaration from setup.h to CI-V.h
2025-05-16 V1 board correction for large radial capacitor. D10mm x L20mm
    Previous 3D mode for large bulk capacitor was incorrect. Updated to right size D10mm x L20mm
    [W4MLB_Band_Display.kicad_pcb]
2025-05-17 1. Modified logic for band detection to avoid repeated queries to the radios unless the bands are in conflict. 2. Added quiet bus checks before transmitting query commands.
    [CI-V.cpp, CI-V.h, main.cpp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]
2025-05-17 Updated code to work with radio queries exclusively.
    Changed how code communicates with radios. Instead of passively listening for CI-V packets, the ESP will now query the radios periodically. This allows for cases where one radio comes online at a lat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
